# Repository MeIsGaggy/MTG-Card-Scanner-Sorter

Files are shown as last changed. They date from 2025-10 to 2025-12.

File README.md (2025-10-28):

# MTG Card Scanner

Using a lightly modified Creality Ender 3 S1, this is designed to be as non-destructive as possible. Every part in this repo can be 3D printed using whatever filament you want, while the stepper motor for the pick-up device is from the Sprite extruder. Everything can be put back together and used it as a 3D printer again. The only hardware I had to buy was vinyl tubing and a bellows suction cup. Both available on Amazon.

---

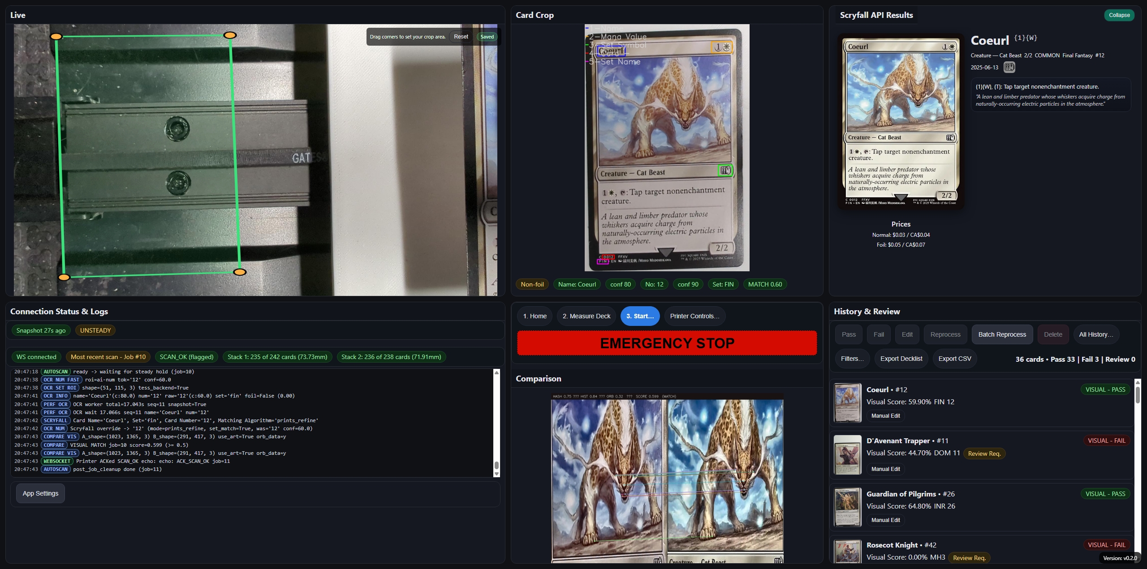
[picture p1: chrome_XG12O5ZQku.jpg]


---

## ⚠️ Disclaimers

* **3D Printer Hardware:** This is designed specifically for an Ender 3 S1. All STL files are modeled from that printer. They will not fit on any other printer. The motion limitations are also desgined for the Ender 3 S1. If you run this on another printer you may damage it.
* **Processing Speed:** This app is not designed to be the fasted available for scanning TCG cards. It was made as a personal project to make minimal modifications to a 3D printer running Klipper to have it sort through my thousands of Magic cards. Apps like Manabox are much faster, however they require manually holding or mounting the phone and running cards under. Even with a 3D printed holder, the reliablity is lackluster at times. This app tried to maintain performance on a Raspberry Pi while trying to keep reliablity as high as possible.
* **AI Assistance:** I am a hobbist, not a professional programmer. I combined my 8+ years of hobby/personal programming with ChatGPT to make something that would have either not been possible given my current skillset or would have taken so long I would have lost interest. If you are not a fan of AI assisted development, please look elsewhere.
* **Reliability:** I've done my best to get this to be as stable and reliable as possible so far. Based on my current testing it will correctly read the card over 90% of the time. Given the odd special foil or layout it may have a hard time. That's why I have a comaparison that runs after the OCR to compare the card scanned to the one it thinks it is. If it's below the set tollerance, it will flag it for manual review. 

---
## 🛠️Testing Hardware

* **Raspberry Pi 5 - 8GB**
* **Creatlity Ender 3 S1 Pro**
* **Google Pixel 7 Pro (as USB Webcam)**

---

## ✨ Features

* **One‑command start** via CLI: `mtg-scanner`
* **Live preview** with ROI (region-of-interest) overlay and steady‑frame auto‑capture
* **Rapid OCR** (RapidOCR ONNX) with optional **Tesseract fallback**
* **Card name matching** (configurable hashing/hist/ORB weights)
* **Scryfall**-powered lookups and price panel (with optional FX rate for CAD)
* **History & exports**: snapshots, thumbnails, and CSV/JSON exports
* **Update check** (optional) against your GitHub Releases on startup
* Designed to run well on **Raspberry Pi** (uses OpenCV headless)

---

## 📦 Installation

### Requirements

* Python **3.9+** (3.11 tested)
* A USB/UVC camera available as `/dev/video*`
* On Raspberry Pi OS / Debian, recommended system packages:

  ```bash
  sudo apt update
  sudo apt install -y tesseract-ocr libatlas-base-dev libjpeg-dev zlib1g-dev
  ```

### Download repository
```bash
gh repo clone MeIsGaggy/MTG-Card-Scanner-Sorter
cd MTG-Card-Scanner-Sorter/
```

### Create a virtualenv and install

From your project root (the folder containing `pyproject.toml`):

```bash
python -m venv .venv && source .venv/bin/activate
pip install --upgrade pip
pip install -e .        # editable install during development
# If OpenCV wheels complain, use headless:
pip uninstall -y opencv-python && pip install opencv-python-headless
```

## 🚨 3D printer running Klipper required!

This app specifically listens for signals from Moonraker. Moonraker runs on Klipper firmware and without it or a 3D printer you must edit the application to listen to mock READ_TO_SCAN signals. The app DOES have this functionality by default, all you need to do is send the SCAN_OK command to the printer and it will act as if it get a good scan from the app.

If you DO have a 3D printer running Klipper, downlaod the printer.cfg located in the repo and put it on your printers Klipper install. That contains all of the macros to use the app in it's current state.

All heaters are disabled in the printer.cfg to prevent fires. Do NOT use any other printer.cfg with this app unless you know what you're doing.

---

## 🔔 Updates

If there is an update available, it will be logged in the apps console. Run the following command to install the update

```bash
pip install --upgrade --force-reinstall \
  "git+https://github.com/MeIsGaggy/MTG-Card-Scanner-Sorter@[VERSION CODE]#egg=mtg_scanner"
```
Where it states [VERSION CODE] you need to paste the vX.X.X from the latest release
---

## 🚀 Quick start (Exports are optional)

```bash
export SETTINGS_PATH="./settings.json"          # optional (defaults to ./settings.json)
export MTG_SCANNER_REPO="<user>/<repo>"        # optional: enables the GitHub update check
mtg-scanner
```

Open a browser to `http://<raspberrypi>:5000` (or whatever host/port you configured).

> settings.json can be created within the app by opening the App Settings then clicking on Save.
> Repo does not need to be set. This is for following my updates, or can be changed to follow your own if you fork

---

## ⚙️ Configuration

Settings are read in this order **(env → `settings.json` → internal defaults)**. You can point the app to a custom config location via `SETTINGS_PATH`.

Create a `settings.json` next to where you run `mtg-scanner` (or copy `src/mtg_scanner/settings.example.json`):

```json
{
  "HOST": "0.0.0.0",
  "PORT": 5000,
  "CAMERA_DEVICE": "/dev/video0",
  "REQ_WIDTH": 1920,
  "REQ_HEIGHT": 1080,
  "REQ_FPS": 30,
  "OCR_BACKEND": "rapidocr,tesseract",
  "OCR_ONLY_ON_SNAPSHOT": true,
  "SHOW_ROI_OVERLAY": true,
  "SCRYFALL_TIMEOUT": 2.5,
  "FX_URL": "https://api.exchangerate.host/latest?base=USD&symbols=CAD",
  "FX_TTL_SEC": 43200,
  "DEBUG_LEVEL": 1
}
```

### Common keys (quick reference)

| Key | Default | What it does |
| --- | ---: | --- |
| `HOST` | `"0.0.0.0"` | Bind address for the web server. Use `127.0.0.1` to restrict to local only. |
| `PORT` | `5000` | Port for the web UI. |
| `CAMERA_DEVICE` | `"/dev/video0"` | Which camera device to open. |
| `REQ_WIDTH` / `REQ_HEIGHT` / `REQ_FPS` | `1920/1080/30` | Camera request settings (driver may choose the closest mode). |
| `OCR_BACKEND` | `"rapidocr,tesseract"` | Backends to try (RapidOCR first, fall back to Tesseract). |
| `OCR_ONLY_ON_SNAPSHOT` | `true` | If `true`, full OCR runs on snapshots; live OCR is throttled for speed. |
| `SHOW_ROI_OVERLAY` | `true` | Draws ROI boxes on the live preview. |
| `MATCH_ENABLE` | `1` | Enables name/image matching. |
| `MATCH_W_HASH`/`MATCH_W_HIST`/`MATCH_W_ORB` | see defaults | Relative weights when comparing frames to the reference. |
| `SCRYFALL_TIMEOUT` | `2.5` | Seconds to wait for Scryfall before skipping. |
| `FX_URL` / `FX_TTL_SEC` | see defaults | FX endpoint and TTL for USD→CAD price conversion. |
| `HISTORY_DIR` | `"./history"` | Where to persist JSON/thumbnail artifacts. |
| `JPEG_QUALITY_SNAP` | `82` | JPEG quality for stored snapshots. |

> Many more tuning options exist (detection thresholds, foil detection, ROI presets, debug switches). The defaults are sane—tune only if you need finer control.

---

## 🖥️ Using the App

The UI is split into panels:

* **Live** — camera feed with ROI overlay. Use the **Snapshot** action to lock a frame for OCR and matching. Live OCR is throttled unless you disable `OCR_ONLY_ON_SNAPSHOT`.
* **Detected Card** — the perspective‑corrected card image and parsed text.
* **Comparison** — quick visual comparison stats and matching scores.
* **Connection & Processing** — camera/processing status and log console. Use **Clear Logs** if needed.
* **Card Info & Prices** — Scryfall details, set symbol, and prices (optionally FX‑converted).

Additional actions:

* **History / Scans** — browse past captures, load a scan, or delete it.
* **Export** — export current/selected results to CSV/JSON (see the Export modal).
* **Settings** — open the settings modal to live‑tweak common options (also persisted via `settings.json`).

---

## 🧰 CLI and environment

* Start the app: `mtg-scanner`
* Override config file location: `export SETTINGS_PATH=/path/to/settings.json`
* Enable update check: `export MTG_SCANNER_REPO=<user>/<repo>`

---

## 🧪 API (advanced)

These are some of the commonly used endpoints that power the UI. Most users don’t need them directly, but they’re handy for automation.

* `GET /` — main UI
* `GET /api/state` — app state & stats
* `POST /api/snapshot` — take a snapshot
* `GET /api/scans` — list saved scans
* `POST /api/scan/<id>/load` — load a scan by id
* `GET /api/scan/<id>/thumb` — thumbnail
* `POST /api/scan/<id>/delete` — delete a scan
* `GET|POST /api/settings` — get/update settings
* `POST /api/logs/clear` — clear in‑app logs
* `GET /api/compare/stats` — comparison metrics
* `POST /api/badlist/add|remove|clear` — manage excluded results

> Endpoints may evolve; use your browser devtools (Network tab) to discover current calls from `ui.js`.

---

## 🛠️ Run as a service (Linux / Raspberry Pi)

Create `/etc/systemd/system/mtg-scanner.service`:

```ini
[Unit]
Description=MTG Scanner
After=network-online.target

[Service]
Type=simple
User=pi
WorkingDirectory=/home/pi/MTG_SCANNER_PROD
Environment=SETTINGS_PATH=/home/pi/MTG_SCANNER_PROD/settings.json
Environment=MTG_SCANNER_REPO=MeIsGaggy/MTG-Card-Scanner-Sorter
ExecStart=/home/pi/MTG_SCANNER_PROD/.venv/bin/mtg-scanner
Restart=on-failure

[Install]
WantedBy=multi-user.target
```

Then enable:

```bash
sudo systemctl daemon-reload
sudo systemctl enable --now mtg-scanner
```

---

## 🧩 Customizing & extending

* **UI tweaks**: edit `templates/index.html`, `static/css/app.css`, and `static/js/ui.js`. No restart is needed for minor CSS/JS in editable installs; otherwise restart the service.
* **Detection/OCR tuning**: adjust thresholds in `settings.json` (e.g., `RECTANGULARITY_MIN`, `TEXT_PRESENCE_MIN`, `MATCH_*` weights). Keep a backup of a good configuration.
* **Alternate currencies**: point `FX_URL` to another base/target pair or disable FX conversion in the UI.
* **Printer / Moonraker hooks**: `MOONRAKER_URL` and `HTTP_POST_URL` exist for optional integrations—leave them as defaults if unused.

## 📄 License

See **LICENSE** in this repository for the license. 

No commercial or for-profit use allowed.

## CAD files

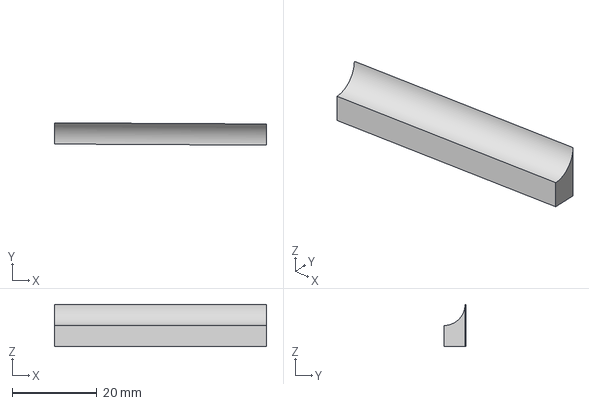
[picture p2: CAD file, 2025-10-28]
GCODE Files - NOT FOR FLASK/Printer Models/base_guide.3mf
50.0 x 5.27 x 10.0 mm

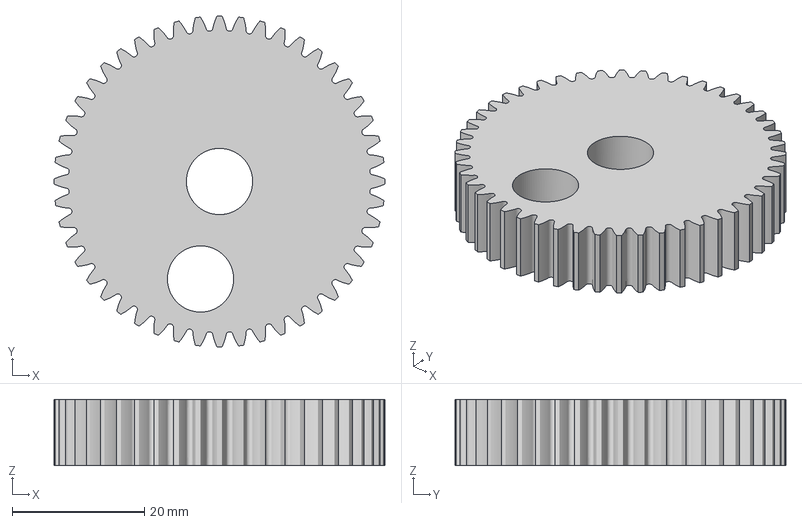
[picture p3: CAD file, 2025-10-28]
GCODE Files - NOT FOR FLASK/Syringe Push and Pull Module/gear_3_crank.3mf
50.0 x 50.0 x 10.0 mm

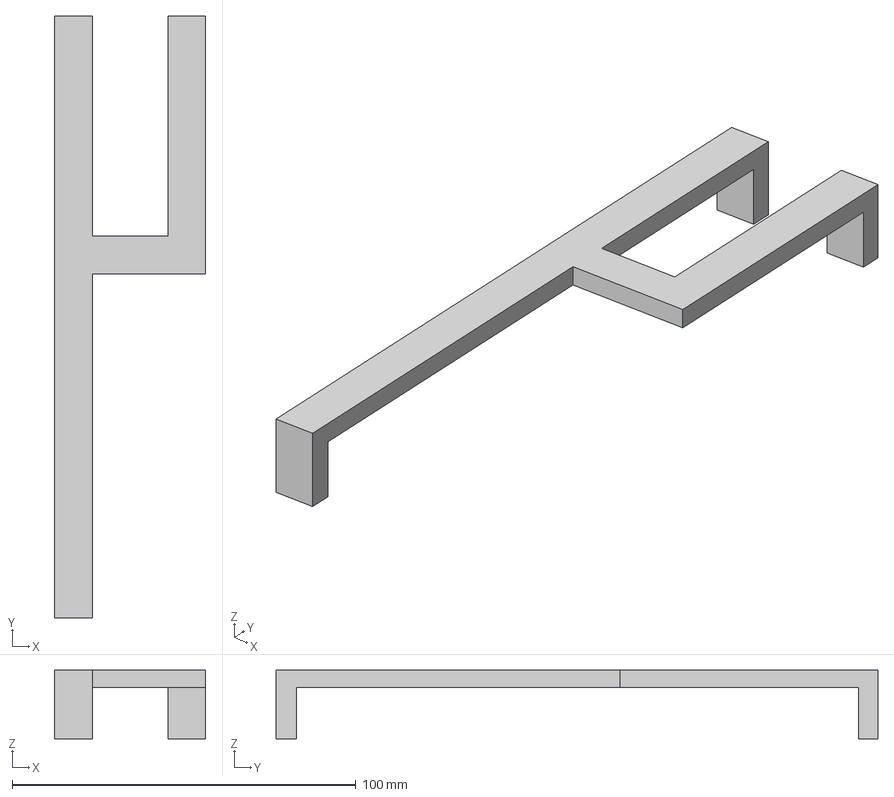
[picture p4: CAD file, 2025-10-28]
GCODE Files - NOT FOR FLASK/Printer Models/phone_lock_bracket.3mf
43.9 x 175.0 x 20.0 mm

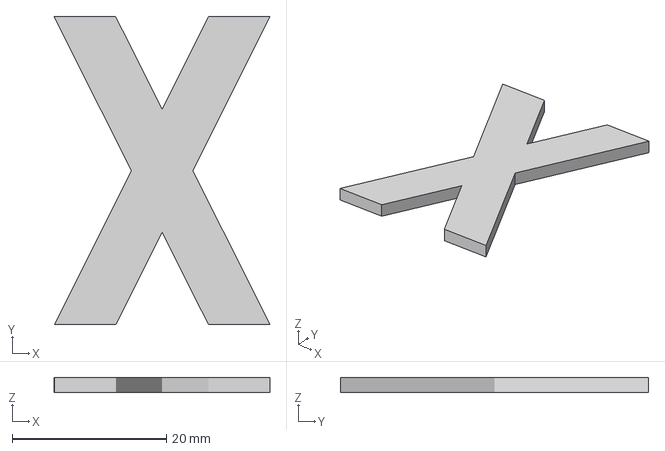
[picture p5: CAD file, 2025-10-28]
GCODE Files - NOT FOR FLASK/Syringe Push and Pull Module/anti_flex_plate.3mf
28.0 x 40.0 x 2.00 mm

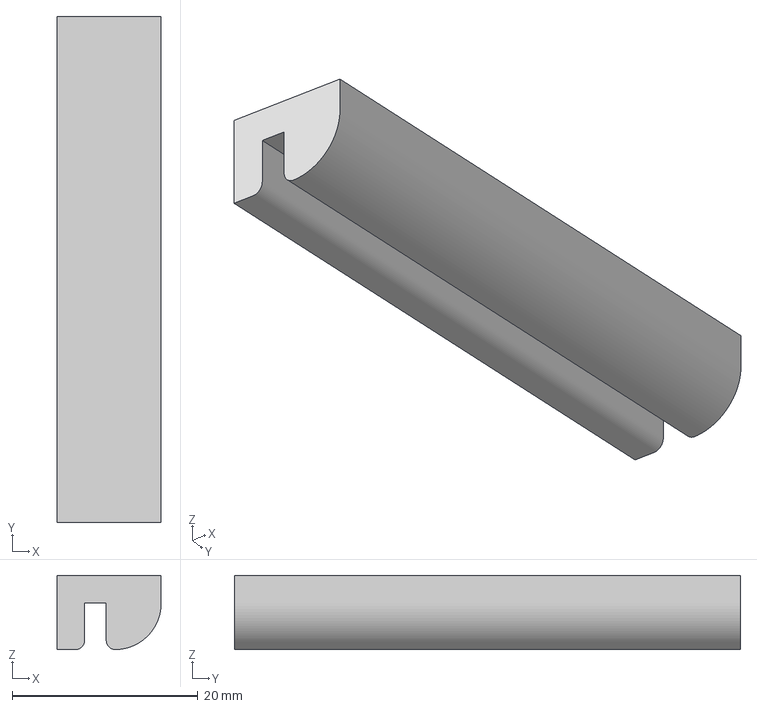
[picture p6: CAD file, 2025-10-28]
GCODE Files - NOT FOR FLASK/Printer Models/card_knocker.3mf
11.2 x 54.5 x 8.00 mm

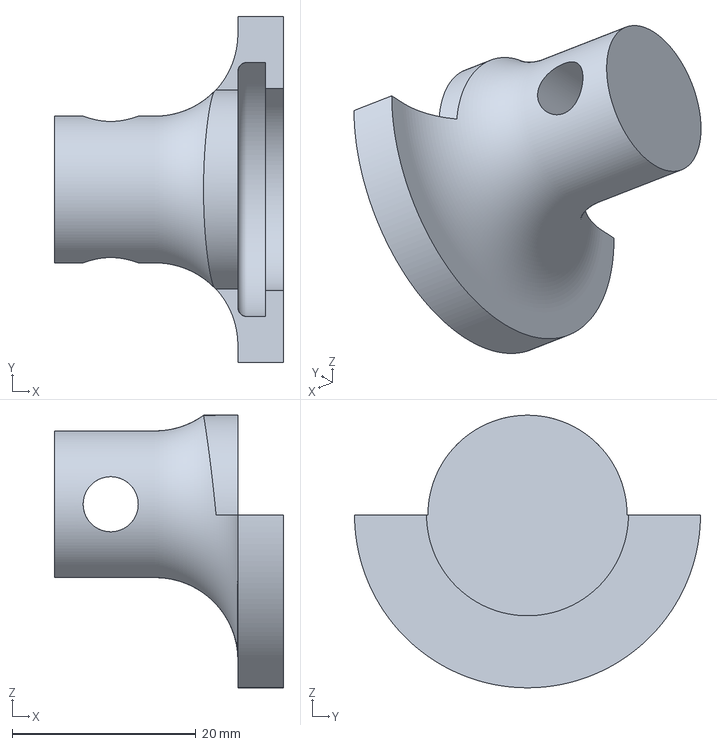
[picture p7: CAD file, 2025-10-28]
GCODE Files - NOT FOR FLASK/Syringe Push and Pull Module/syringe_plunger_adapter.3mf
25.0 x 37.7 x 29.7 mm

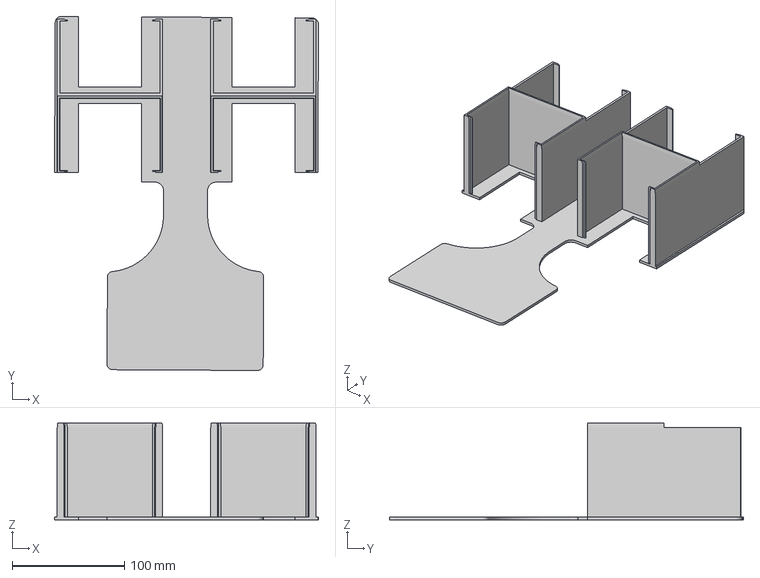
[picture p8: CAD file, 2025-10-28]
GCODE Files - NOT FOR FLASK/Printer Models/base_2_start_stack.3mf
235.7 x 315.9 x 86.5 mm

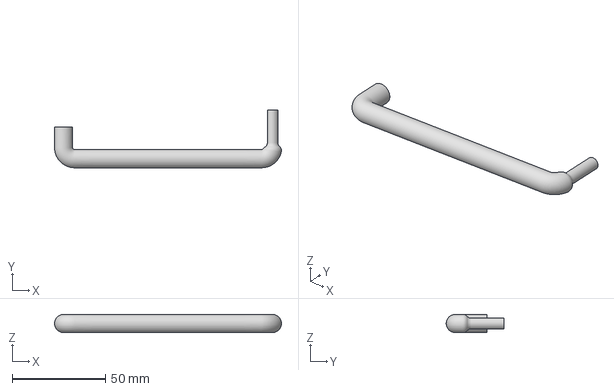
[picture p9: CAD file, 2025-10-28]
GCODE Files - NOT FOR FLASK/Syringe Push and Pull Module/crank_shaft.3mf
121.5 x 30.8 x 9.75 mm

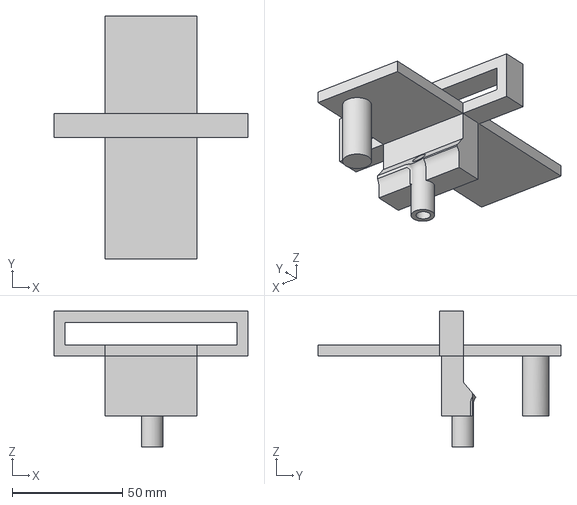
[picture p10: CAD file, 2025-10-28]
GCODE Files - NOT FOR FLASK/Printer Models/phone_holder_and_tube_guide.3mf
87.8 x 110.0 x 61.3 mm

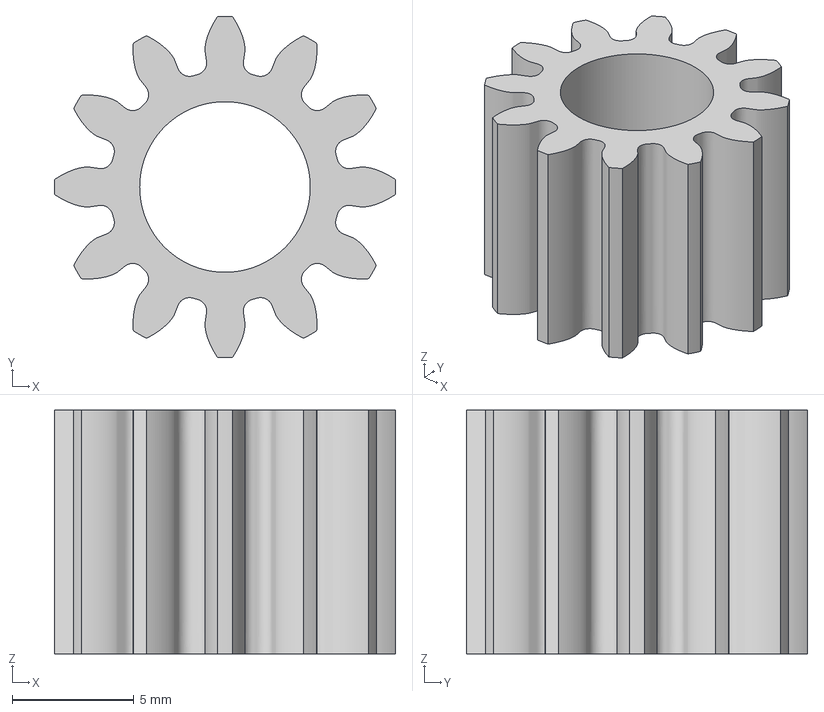
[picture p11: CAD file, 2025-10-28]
GCODE Files - NOT FOR FLASK/Syringe Push and Pull Module/gear_1_to_stepper.3mf
14.0 x 14.0 x 10.0 mm

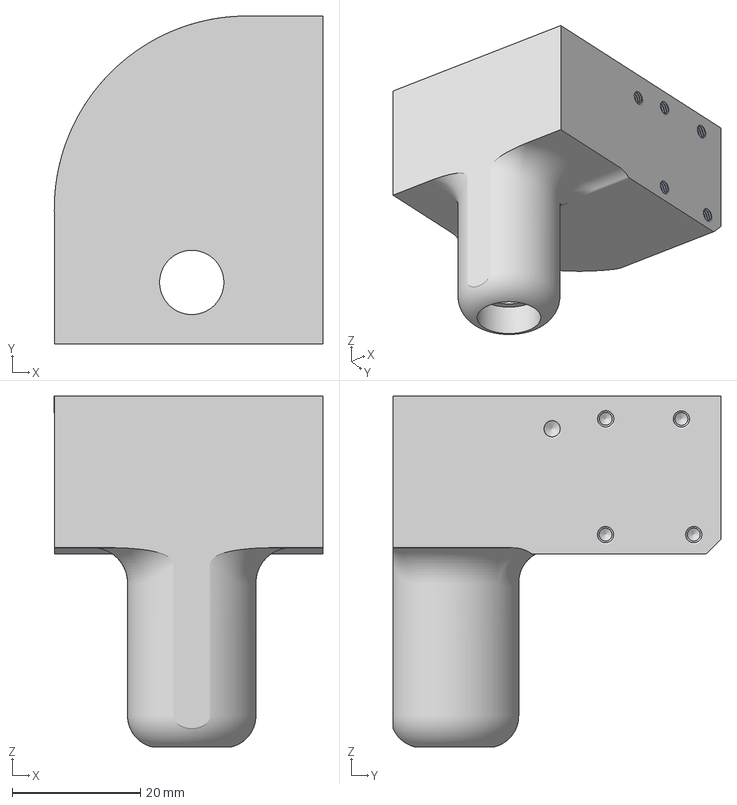
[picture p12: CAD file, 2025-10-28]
GCODE Files - NOT FOR FLASK/Printer Models/suction_head.3mf
41.8 x 51.1 x 54.6 mm

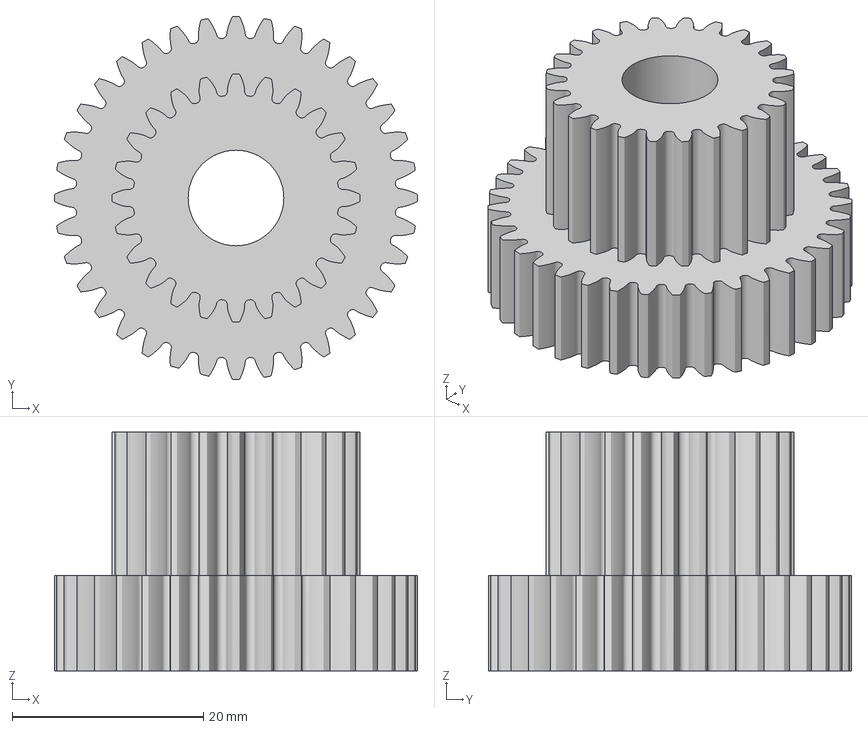
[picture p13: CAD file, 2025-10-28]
GCODE Files - NOT FOR FLASK/Syringe Push and Pull Module/gear_2_intermediate.3mf
38.0 x 38.0 x 25.0 mm

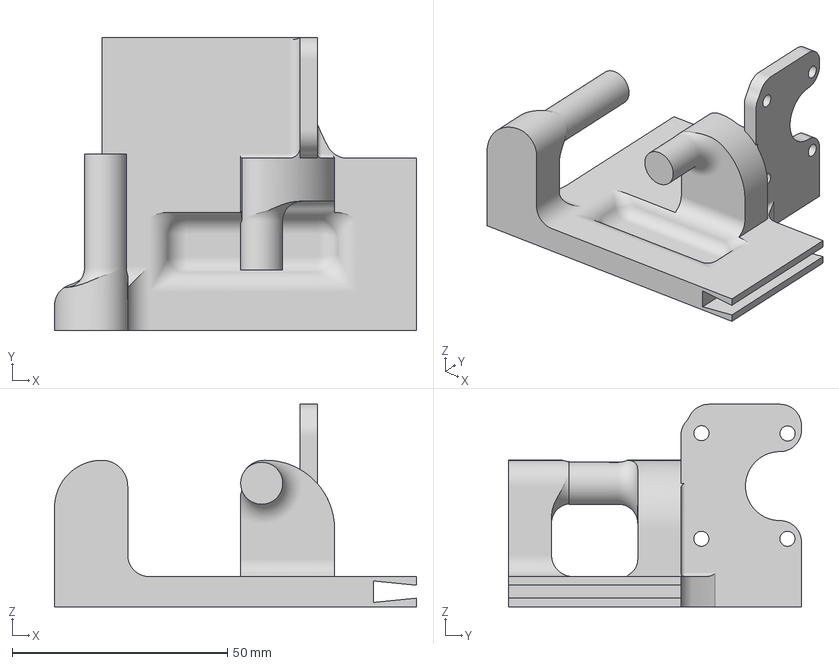
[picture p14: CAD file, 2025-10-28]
GCODE Files - NOT FOR FLASK/Syringe Push and Pull Module/stepper_gear_base.3mf
84.0 x 68.0 x 47.0 mm

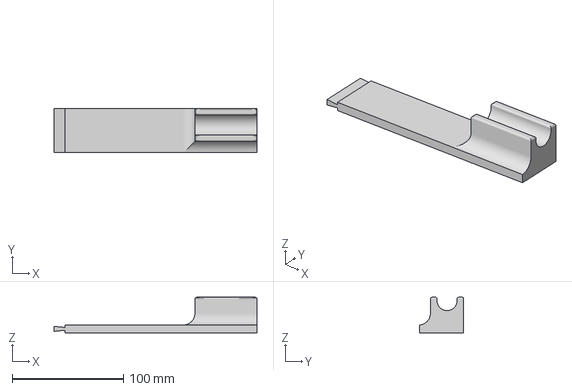
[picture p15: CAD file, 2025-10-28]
GCODE Files - NOT FOR FLASK/Syringe Push and Pull Module/syringe_base.3mf
182.7 x 40.0 x 32.0 mm

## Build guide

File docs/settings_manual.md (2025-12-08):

# Settings Reference (MTG Scanner)

How values flow: environment variables override `settings.json`, which overrides built‑in defaults in `config.py`. The UI reads from `/api/settings` and writes back to `settings.json`; most changes take effect immediately unless noted. Camera device/size/FPS and server bind (`HOST`/`PORT`) typically need a restart.

## Camera
- `CAMERA_DEVICE` — Video device path (e.g., `/dev/video0`).
- `REQ_WIDTH` / `REQ_HEIGHT` — Requested capture resolution; restart required.
- `REQ_FPS` — Requested capture frame rate; restart required.
- `FOURCC_PRIMARY` / `FOURCC_FALLBACK` — Preferred/backup pixel format codes.

## Processing & Canvas
- `PROC_MAX_WIDTH` / `PROC_DOWNSCALE_MAX_W` — Max width for processing and pre-detection downscale.
- `CARD_W` / `CARD_H` — Canvas size used for warping the card crop.
- `MIN_CARD_AREA_RATIO` / `MAX_CARD_AREA_RATIO` — Allowed card area as fraction of frame.
- `BORDER_MARGIN_PCT` — Padding around detected card to keep margins.
- `CARD_ASPECT` / `ASPECT_TOL` — Target aspect ratio and tolerance.
- `RECTANGULARITY_MIN` — Minimum rectangle score for a valid quad.
- `CARD_DETECT_MIN_SCORE` — Minimum score to treat a contour as a card.
- `CARD_RING_OUTSIDE_MIN_FRAC` — Required fraction of border that must live outside the card.
- `DETECT_QUAD_PAD_PCT` — Extra padding applied to detection quads before warp.
- `CARD_BG_BLUR` — Blur kernel size for background smoothing.
- `CARD_CLAHE_CLIP` / `CARD_CLAHE_TILE` — CLAHE parameters for card normalization.
- `CARD_BLACKHAT_KERNEL` — Kernel size for blackhat preprocessing on card masks.
- `CARD_CHANNEL_THRESH_C` — Constant added during channel thresholding.
- `CARD_MASK_MIN_COMPONENT` — Minimum connected component size for card masks.
- `CARD_MASK_BORDER_TRIM_PCT` — Border trim on masks to avoid edge artifacts.
- `CARD_EDGE_MIN_STRENGTH` / `CARD_EDGE_MIN_CONTRAST` / `CARD_EDGE_RING_FRAC` — Edge strength/contrast/ring guards for borders.
- `CARD_EDGE_SNAP_FRAC` — Snap factor when aligning detected edges.
- `CARD_EDGE_CONTRAST_WEIGHT` / `CARD_EDGE_CONTRAST_STEP` — Weight and step size when searching for edge contrast.
- `CARD_CROP_LIVE` — If false, keep the full frame in the live feed instead of the cropped card.
- `QUAD_STICKY_PX` — Pixel hysteresis applied to quad movement.
- `QUAD_SMOOTH_MIN_ALPHA` / `QUAD_SMOOTH_MAX_ALPHA` — Bounds for quad smoothing strength.
- `MANUAL_CROP_ENABLED` / `MANUAL_CROP_QUAD` — Enable and set manual quad points (UI drag handles).

## Tracking, Steady, Autoscan
- `CONFIRM_FRAMES` / `STALE_FRAMES` — Frames to confirm a card and to drop stale tracks.
- `MAX_ASSOC_DIST` — Max pixel distance to associate detections to tracks.
- `MAX_CARDS` — Limit of concurrent card tracks.
- `STEADY_MIN_FRAMES` / `STEADY_RELAX_FRAMES` — Frames required for steady state and relaxation.
- `STEADY_PROMOTE_S` — Time in steady before autoscan promotion.
- `AUTO_CAPTURE_WAIT_S` — Delay after READY_TO_SCAN before the snapshot (lets the stream settle).
- `AUTOSCAN_OCR_TIMEOUT` — Timeout for OCR after the snapshot.
- `DETECT_EVERY_N_FRAMES` / `DETECT_MAX_FPS` — Detection cadence caps.
- `FOIL_EVERY_N_FRAMES` — Interval for foil detection passes.
- `STEADY_SPEED_PX` — Speed threshold (px/frame) for steady detection.
- `LOCK_IOU_THRESH` — IoU threshold to lock a track to a detection.
- `ACQUIRE_FRAMES` / `DROP_MISS_FRAMES` / `PREDICT_HOLD` — Frames to acquire, drop, and hold predictions for a track.
- `TRACK_ALPHA` / `TRACK_BETA` / `TRACK_DEADBAND_PX` — Tracker smoothing and deadband weights.
- `TRACK_BOX_BLEND` — Blend factor when merging track boxes with new detections.
- `WARP_EXPAND_PCT` / `WARP_CROP_PCT` — Expand/crop percentages around warped cards.
- `MANUAL_SCAN_BYPASS_STEADY` — Allow manual scan without steady check.
- `FAST_OCR_MODE` — Favor speed for autoscan OCR.

## Capture & Orientation
- `SNAPSHOT_CARD_SCALE` — Upsample factor applied to saved/ocr snapshots.
- `AUTO_ORIENT` — Enable automatic card orientation.

## OCR & Debug
- `OCR_BACKEND` — Comma list of OCR backends to try.
- `OCR_ONLY_ON_SNAPSHOT` — If true, OCR only on captured snapshot (not live).
- `DEBUG_OCR` — Emit OCR debug logs.
- `OCR_DEBUG_BOXES` — Draw OCR boxes in the UI.
- `SHOW_ROI_OVERLAY` — Draw ROI overlays.
- `MIN_TITLE_LETTERS` — Minimum title length to accept.
- `TEXT_PRESENCE_MIN` — Text presence threshold for detecting text regions.
- `TITLE_ALLOW_TESS_FALLBACK` — Allow Tesseract fallback when primary fails.
- `USE_TESS_FOR_TITLES` — Force Tesseract for titles.
- `OCR_ENABLE_BLACKHAT` — Enable blackhat preprocessing on OCR crops.
- `LIVE_OCR_ONLY_WHEN_STEADY` / `LIVE_OCR_MIN_INTERVAL` — Gate live OCR to steady state and rate limit it.
- `OCR_SKIP_NUMBER` / `OCR_FAST_NUMBER_CONF_EXIT` — Skip collector number OCR or early-exit by confidence.
- `CARD_STREAM_LIVE` / `LIVE_CROP_WHILE_PAUSED` — Control live card crop display and whether the crop updates while paused.

## OCR Fast Path & Reprocess
- `OCR_FAST_PATH` / `OCR_LAZY_SET_HINT` — Enable fast OCR path and reuse set hints.
- `OCR_TITLE_SINGLE_PASS` — Single-pass title OCR (skip second attempt).
- `OCR_USE_EASYOCR` — Use EasyOCR shortcut flow.
- `OCR_TITLE_MAX_W` — Max width for title crop in fast path.
- `OCR_NUMBER_FASTPATH` — Enable fast-path number OCR.
- `REPROCESS_FORCE_FAST_OCR` — Force fast OCR during reprocess.
- `REPROCESS_MAX_WIDTH` — Downscale snapshot width before re-OCR (0 = off).
- `REPROCESS_SKIP_AI_ROIS` — Skip AI ROI refresh during reprocess.
- `REPROCESS_SKIP_FOIL_DETECT` — Skip foil detect during reprocess.

## Foil Detection
- `FOIL_MIN_SCORE` — Minimum foil score to consider foil.
- `FOIL_ON_TH` / `FOIL_OFF_TH` — Hysteresis thresholds to toggle foil state.
- `FOIL_DETECT` — Enable foil detection.

## Match / Comparison
- `MATCH_ENABLE` — Enable visual matching.
- `MATCH_W_HASH` / `MATCH_W_HIST` / `MATCH_W_ORB` — Weights for hash, histogram, and ORB scores.
- `MATCH_TH` — Overall match pass threshold.
- `NAME_OK_TH` — Name similarity threshold.
- `ALWAYS_SCAN_OK` — Force scan OK even if match fails.
- `MATCH_USE_ART` — Include art region in comparison.
- `MATCH_REQUIRE_ORB` — Require ORB match to pass.
- `MATCH_ORB_FAIL_THRESHOLD` — Threshold to flag ORB failure.
- `MATCH_ORB_FEATURES` — Number of ORB features to extract.
- `MATCH_FAST_ACCEPT_DELTA` / `MATCH_FAST_REJECT_DELTA` — Early accept/reject margins.
- `HASH_STABILITY_BITS` — Bits that must change before re-OCR triggers.

## Stream / UI Feeds
- `STREAM_ENABLED` — Enable MJPEG streaming.
- `STREAM_FPS` — Stream frame rate; defaults to camera FPS.
- `STREAM_JPEG_QUALITY` — JPEG quality for stream frames.
- `STREAM_WARP_DOWNSCALE` — Downscale factor before warping for stream only.
- `STREAM_CARD_SCALE` — Scale for card crop in UI stream.
- `SNAPSHOT_CARD_SCALE` — Upsample factor for saved/ocr snapshots.
- `CARD_STREAM_LIVE` / `LIVE_CROP_WHILE_PAUSED` — Send live card crops and keep updating while paused.
- `CARD_CROP_LIVE` — Show cropped card in the live feed instead of the full frame.

## Moonraker / Klipper
- `MOONRAKER_URL` — WebSocket URL to Moonraker.
- `HTTP_POST_URL` — HTTP endpoint for G-code script posting.
- `REQUIRE_PRINTER_ACK` — Wait for printer ACK before proceeding.

## Stacks / Sorter
- `CARD_THICKNESS_MM` — Card thickness estimate pushed to Klipper.
- `REMEASURE_EVERY` — Cards between auto re-measure; 0 disables mid-run probe.

## AI / YOLOv5
- `AI_ENABLED` — Master AI toggle.
- `AI_USE_FOR_CARDS` / `AI_USE_FOR_ROIS` — Use AI to find card box / ROIs.
- `AI_ONLY_MODE` — Use AI ROIs only (ignore static ROIs).
- `AI_MODEL_PATH` — Path to YOLO model.
- `YOLOV5_DIR` — Local YOLOv5 repo path.
- `AI_IMG_SIZE` — Inference image size.
- `AI_CONF_THRES` / `AI_IOU_THRES` — Confidence and IoU thresholds.
- `AI_MAX_DETS` — Maximum detections per inference.
- `AI_CLASS_NAMES` — Class labels list (order-sensitive).
- `AI_BOX_THICKNESS` / `AI_LEGEND_FONT_SCALE` / `AI_LEGEND_FONT_THICKNESS` / `AI_LEGEND_LINE_THICKNESS` / `AI_LEGEND_PAD` — Overlay settings for AI debugging legends.
- `AI_CARD_MIN_CONF`, `AI_SETNAME_MIN_CONF`, `AI_SETNAME_MIN_Y`, `AI_SETNAME_MAX_Y`, `AI_SETNAME_MIN_WIDTH`, `AI_SETNAME_MIN_HEIGHT`, `AI_CARD_MIN_AREA`, `AI_CARD_MAX_TOP` — Heuristics to filter detections by confidence, position, and size.
- `AI_NAME_PAD_X` / `AI_NAME_PAD_Y` — Padding applied to name ROI.
- `AI_TOPLINE_FRAC_MIN` / `AI_TOPLINE_MULT` — Heuristics for merging text lines.
- `AI_CARD_PAD_LEFT` / `AI_CARD_PAD_RIGHT` / `AI_CARD_PAD_Y` — Extra padding around detected cards before ROI extraction.
- `SET_ICON_FALLBACK_ENABLE` / `SET_NAME_FALLBACK_ENABLE` — Fall back to set icon/name heuristics when OCR fails.

## Export & Caches
- `EXPORT_DIR` — Export output directory.
- `SC_IMG_CACHE_DIR` — Scryfall image cache directory.
- `SCRY_IMG_LRU_MAX` / `SCRY_FEATS_LRU_MAX` — In-memory LRU sizes for images/features.
- `SCRY_SETS_CACHE_PATH` / `SCRY_SETS_CACHE_TTL_S` — Cache path and TTL for Scryfall set data.

## Scryfall & Prices
- `SCRYFALL_TIMEOUT` — HTTP timeout for Scryfall calls.
- `FX_URL` — Exchange rate API URL.
- `FX_TTL_SEC` — Cache TTL for FX data.

## Appearance / Photometric
- `APPEARANCE_ALIGN_ENABLE` — Enable appearance alignment.
- `APPEARANCE_AB_STRENGTH` / `APPEARANCE_SAT_STRENGTH` — Chroma and saturation match strengths.
- `APPEARANCE_GAMMA_CLAMP` — Allowed gamma clamp range.
- `TONE_ALIGN_ENABLE` — Enable tone alignment.

## Persistence & Server
- `HISTORY_DIR` / `HISTORY_IMG_DIR` — History storage paths.
- `HISTORY_JSON_EXT` — Extension for history JSON files.
- `JPEG_QUALITY_SNAP` / `JPEG_QUALITY_CMP` / `JPEG_QUALITY_THUMB` — JPEG qualities.
- `HISTORY_API_DEFAULT_LIMIT` / `HISTORY_API_MAX_LIMIT` — API pagination limits.
- `HOST` / `PORT` — Server bind address/port; restart required.

## Debug / Paths / Performance
- `DEBUG_LEVEL` — Verbosity level.
- `DEBUG_SAVE_ROI` — Save ROI crops.
- `DEBUG_DIR` — Directory for debug artifacts.
- `BAD_DIR` — Directory for bad-list images.
- `USE_OPENCL` — Allow OpenCL acceleration when available.

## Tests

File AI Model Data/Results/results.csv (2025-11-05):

epoch | train/box_loss | train/obj_loss | train/cls_loss | metrics/precision | metrics/recall | metrics/mAP_0.5 | metrics/mAP_0.5:0.95 | val/box_loss | val/obj_loss | val/cls_loss | x/lr0 | x/lr1 | x/lr2
0 | 0.10964 | 0.039257 | 0.04689 | 0.005422 | 0.26599 | 0.01826 | 0.004048 | 0.086834 | 0.035313 | 0.03565 | 0.0748 | 0.0028 | 0.0028
1 | 0.085968 | 0.039998 | 0.032323 | 0.26259 | 0.29595 | 0.05763 | 0.021313 | 0.08709 | 0.029912 | 0.025139 | 0.048644 | 0.0056436 | 0.0056436
2 | 0.078617 | 0.034368 | 0.023455 | 0.07547 | 0.27515 | 0.06904 | 0.013564 | 0.090034 | 0.023735 | 0.017189 | 0.02243 | 0.0084297 | 0.0084297
3 | 0.077252 | 0.028146 | 0.017608 | 0.2987 | 0.74466 | 0.47203 | 0.15206 | 0.068803 | 0.02081 | 0.013595 | 0.009703 | 0.009703 | 0.009703
4 | 0.071493 | 0.024177 | 0.01427 | 0.42542 | 0.54384 | 0.37361 | 0.11619 | 0.066754 | 0.018996 | 0.0087561 | 0.009703 | 0.009703 | 0.009703
5 | 0.066223 | 0.022305 | 0.01041 | 0.41079 | 0.90771 | 0.57121 | 0.15114 | 0.069385 | 0.016911 | 0.0061492 | 0.009604 | 0.009604 | 0.009604
6 | 0.059028 | 0.02084 | 0.0086906 | 0.41022 | 0.88958 | 0.52366 | 0.18978 | 0.057659 | 0.014983 | 0.004865 | 0.009505 | 0.009505 | 0.009505
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

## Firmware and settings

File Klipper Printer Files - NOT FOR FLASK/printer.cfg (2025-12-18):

# ============================== CARD SCANNER CONFIG (Ender 3 S1 + Klipper) ==============================
# Motion-only setup for MTG card sorting. Heaters/fans are neutralized. Scanner app drives pass/fail.

[delayed_gcode INIT_VAC_ZERO]
initial_duration: 1
gcode:
  # Define current physical position as OFF=0 at firmware start
  MANUAL_STEPPER STEPPER=VAC SET_POSITION=0

# ===== UI Helpers =====
[gcode_macro SORTER_HELP]
description: Show the short how-to for the card scanner
gcode:
  { action_respond_info(
    "CARD SCANNER — Quick start:\\n"
    "1) SORTER_HOME (or RUN_SORTER_INTERACTIVE COUNT=1 HOME=1)\\n"
    "2) SET_START_HEIGHT_GUIDED  -> then SET_START_HEIGHT_OK (measures Start1 & Start2)\\n"
    "3) SORT_ONE (or SORT_10). While at scan, your app sends SCAN_OK / SCAN_FAIL.\\n"
    "Useful: SHOW_STACKS, CANCEL_SCAN_WAIT, SET_TIMEOUT_S VALUE=<sec> (0=infinite)"
  ) }

[gcode_macro SORT_ONE]
description: Pick 1 card and run one full scan/place cycle
gcode:
  RUN_SORTER_INTERACTIVE COUNT=1 HOME=0

[gcode_macro SORT_10]
description: Pick and process 10 cards
gcode:
  RUN_SORTER_INTERACTIVE COUNT=10 HOME=0

[gcode_macro SET_TIMEOUT_S]
description: Set scan wait timeout (seconds). 0 = wait forever (no auto-fail)
gcode:
  {% set V = params.VALUE|default(0)|int %}
  SET_GCODE_VARIABLE MACRO=SORTER_PARAMS VARIABLE=scan_timeout_s VALUE={V}
  { action_respond_info("Scan timeout set to %s" % ("infinite" if V==0 else ("%ds" % V))) }

[gcode_macro CANCEL_SCAN_WAIT]
description: Cancel any active scan wait / countdown ticks
gcode:
  SET_GCODE_VARIABLE MACRO=VISION_STATE VARIABLE=busy VALUE=0
  SET_GCODE_VARIABLE MACRO=VISION_STATE VARIABLE=timer_left  VALUE=0
  SET_GCODE_VARIABLE MACRO=VISION_STATE VARIABLE=timer_total VALUE=0
  UPDATE_DELAYED_GCODE ID=VISION_TIMEOUT DURATION=0
  UPDATE_DELAYED_GCODE ID=VISION_TICK    DURATION=0
  RESPOND PREFIX=info MSG="Scan wait cancelled."

# ===== Includes / Core =====
[include fluidd.cfg]
# [include timelapse.cfg]

[mcu]
serial: /dev/serial/by-id/usb-1a86_USB_Serial-if00-port0
restart_method: command

[printer]
kinematics: cartesian
max_velocity: 100
max_accel: 750
max_z_velocity: 100
max_z_accel: 500
square_corner_velocity: 5.0

# ----- Axes -----
[stepper_x]
step_pin: PC2
dir_pin: PB9
enable_pin: !PC3
microsteps: 16
rotation_distance: 40
endstop_pin: !PA5
position_endstop: -10
position_max: 235
position_min: -15
homing_speed: 50

[stepper_y]
step_pin: PB8
dir_pin: PB7
enable_pin: !PC3
microsteps: 16
rotation_distance: 40
endstop_pin: !PA6
position_endstop: -8
position_max: 240
position_min: -13
homing_speed: 50

[stepper_z]
step_pin: PB6
dir_pin: !PB5
enable_pin: !PC3
microsteps: 16
rotation_distance: 8
endstop_pin: probe:z_virtual_endstop
position_max: 270
position_min: -10
homing_speed: 10

# ----- Probe (BLTouch) -----
[bltouch]
sensor_pin: ^PC14
control_pin: PC13
x_offset: -31.8
y_offset: -40.5
z_offset: 4.085
probe_with_touch_mode: true
stow_on_each_sample: false
samples: 1
samples_tolerance: 0.1
samples_tolerance_retries: 2
speed: 20.0

# === Custom safe home (unchanged) ===
[homing_override]
set_position_z: 0
axes: xyz
gcode:
  G90
  G1 Z75 F1200
  G28 X Y
  G1 X104 Y10 F6000
  G28 Z

# Optional: bed mesh
[bed_mesh]
speed: 120
mesh_min: 10, 10
mesh_max: 200, 194
probe_count: 4,4
algorithm: bicubic
fade_start: 1
fade_end: 10
fade_target: 0

# ----- QoL -----
[respond]
[display_status]
[pause_resume]
recover_velocity: 25
[idle_timeout]
timeout: 1800

[temperature_sensor raspberry_pi]
sensor_type: temperature_host
min_temp: 10
max_temp: 100

# ----- Neutralize print-related G-codes -----
[gcode_macro M104]
description: NO-OP (heating disabled)
gcode:
  RESPOND PREFIX=warn MSG="M104 ignored: heaters disabled"

[gcode_macro M109]
description: NO-OP (heating disabled)
gcode:
  RESPOND PREFIX=warn MSG="M109 ignored: heaters disabled"

[gcode_macro M140]
description: NO-OP (bed heating disabled)
gcode:
  RESPOND PREFIX=warn MSG="M140 ignored: bed disabled"

[gcode_macro M190]
description: NO-OP (bed heating disabled)
gcode:
  RESPOND PREFIX=warn MSG="M190 ignored: bed disabled"

[gcode_macro M106]
description: NO-OP (fans repurposed later)
gcode:
  RESPOND PREFIX=info MSG="M106 ignored: fans disabled"

[gcode_macro M107]
description: NO-OP
gcode:
  RESPOND PREFIX=info MSG="M107 ignored: fans disabled"

# ===== Sorter Coordinates / Motion Tunables =====
[gcode_macro SORTER_PARAMS]
# --- SCAN AREA (single) ---
variable_scan_xy:     118.0, 0.0  # one scan area only
# --- REJECT AREA (single) ---
variable_reject_xy:    53.80, 61.0

# --- LEGACY single-stack aliases (kept for compatibility; not used by new logic) ---
variable_input_xy:    120.0, 220.0
variable_finish_xy:    53.80, 61.0

# --- NEW: dual starts & dual finishes (EDIT THESE 4) ---
variable_input1_xy:   44.0, 225.0   # Start stack 1  ← set yours
variable_input2_xy:   181.0, 225.0   # Start stack 2  ← set yours
variable_finish1_xy:   45.0, 156.30   # Finish stack 1 ← set yours
variable_finish2_xy:   182.20, 156.30  # Finish stack 2 ← set yours

# Tool XY offset if your picker isn't centered to nozzle coords
variable_tool_offset_x: 0.0
variable_tool_offset_y: 0.0

# Heights & speeds
variable_clearance_z: 60.0         # minimum safe Z
variable_travel_z:    110.0         # travel height for XY moves while holding a card
variable_approach_z:  2.0
variable_pick_z:      -0.25
variable_place_z:     0.8
variable_pick_guard:  -2.5
variable_min_z_floor: -3.0
variable_empty_z:      4.0           # <= this Z means "no card"

# Scan plane & head park pose (single scan area)
variable_scan_drop_z:   0.0           # Z where the card rests for scanning (bed plane)
variable_scan_pick_delta:   0.0           # +mm press when picking from scan (0 = same as drop)
variable_scan_head_xy: 124.0, 117.0   # HEAD PARK XY during scan
variable_scan_head_z:  70.0          # HEAD PARK Z during scan
variable_finish_drop_z: 88.085          # Z to drop card for PASS
variable_reject_drop_z: 88.085          # Z to drop card for FAIL
variable_scan_h:        0.0           # legacy (not used for motion)
variable_xy_speed:    7000
variable_z_speed:     1250

# Timings (ms)
variable_dwell_pick_ms:     500
variable_dwell_scan_ms:     500
variable_dwell_release_ms:  200
variable_lift_after_pick:    75.0
variable_dwell_drop_ms:     500

# Probe speeds
variable_probe_fast: 100.0
variable_probe_slow: 50.0

# Vacuum tuning — simple symmetric half-turns
variable_vac_half_rev: 12.741
variable_vac_speed:    15
variable_vac_dwell_ms: 120
variable_pick_z_start: -2.5

# Shake (hitchhiker guard)
variable_shake_enable:        1
variable_shake_lift:          2.5
variable_shake_duration_ms:   500
variable_shake_step:          0.10
variable_shake_pulse_ms:      10
variable_shake_speed:         8000
variable_shake_accel:         8000

# Scan wait behavior
variable_scan_timeout_s:    0
variable_scan_warn_step_s: 10
variable_timeout_auto_fail: 0
gcode:
  G4 P0

# ===== Dynamic Stack Heights (DUAL) =====
[gcode_macro STACK_STATE]
variable_card_thickness: 0.305
variable_cards1_total: 0
variable_cards2_total: 0
variable_cards_since_measure: 0
variable_remeasure_every: 0
variable_last_meas1: 0.0
variable_last_meas2: 0.0
variable_last_cards1: 0
variable_last_cards2: 0
variable_start1_cards_est: 0.0
variable_start2_cards_est: 0.0
# start stacks (measured separately)
variable_start1_h: 0.0
variable_start2_h: 0.0
variable_start1_empty: 0
variable_start2_empty: 0
variable_last_probe_z: 0.0
variable_last_probe_slot: 0
variable_pending_pick: 0
# finish stacks (running totals)
variable_finish1_h: 0.0
variable_finish2_h: 0.0
variable_reject_h:  0.0
# which stack to pick next / which finish to drop next
variable_next_start_slot: 1
variable_next_finish_slot: 1
# source start slot of the *current* card (set by PICKUP_CARD)
variable_src_slot: 0
gcode: G4 P0

# ===== Vacuum Plunger Stepper (compound 1->3, 2->4; 3/2 same axle) =====
[manual_stepper VAC]
step_pin: PB4
dir_pin: PB3                      # ON = +X, OFF = −X (non-inverted)
enable_pin: !PC3
microsteps: 16
rotation_distance: 25.482
gear_ratio: 3:1, 2:1              # overall 6:1
full_steps_per_rotation: 200
velocity: 100
accel: 400
position_min: -200
position_max:  200

# ===== Setup / Calibration =====
[gcode_macro SORTER_HOME]
description: Home and raise to safe Z
gcode:
  G90
  G28
  _STOW_PROBE
  _SAFE_RAISE
  RESPOND PREFIX=info MSG="Homed. Stack probe will measure each pickup."

[gcode_macro SET_START_HEIGHT_GUIDED]
description: Move to safe Z and prompt to place start stacks
gcode:
  {% set P = printer["gcode_macro SORTER_PARAMS"] %}
  G90
  {% if printer.toolhead.position.z|float < P.clearance_z %}
    G1 Z{P.clearance_z} F{P.z_speed}
  {% endif %}
  G1 Z100 F{P.z_speed}
  RESPOND PREFIX=info MSG="Place BOTH START stacks, then run: SET_START_HEIGHT_OK"
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

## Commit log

2025-08-23 Added printer config file
    [printer.cfg]
2025-08-23 Updated printer.cfg
    [printer.cfg]
2025-10-05 New 2-stack sorting
    - Added logic for picking from two stacks intead of one
    - Added logic for dropping into two stacks intead of one
    - Stacks one and two are alternated while picking and dropping
    - Added printer motion controls with a D-pad style control scheme
    - Added emergency stop to shutdown printer
    - Added card detection ROI memory (when ROI is set it persists through app restarts)
    [printer.cfg]
2025-10-06 v0.1 STL models
    This entire program is designed around the use of these files.
    [anti_flex_plate.3mf, base_2_start_stack.3mf, base_guide.3mf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]
2025-11-05 v0.1.5 - AI Detection
    Now uses a trained AI model to detect keys on MTG cards instead of hard-coded ROIs for OCR
    AI was trained on a Raspberry Pi 5 with the only non-stock addition being an NVME HAT
    App has fallback logic for alternator layouts. If there is no set code or collector number detected, it will use the set icon if it detects it then compares that icon to a known list of icons. This i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
    App can run on its own with little to no intervention. The odd card gets dropped at an odd angle and needs to be adjusted
    [results.csv]
2025-12-08 v0.2 - Major improvements App: - Reworked live stream detection to simple snapshot within set ROI by the user (card detection was being annoying and unstable) - Removed unused logic - Increased relia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
    [printer.cfg]
2025-12-18 v0.2.1 - Batch Reprocessing, New Pick Logic and Bux Fixes
    - Implemented batch reprocessing. Failed cards are counted, queued for reprocess then reprocessed one by one. The user is presented with a list of each card upon completion
    - Implemented quarantine review for bad json saves. Includes auto-fix but also has fields to manually edit
    - Fixed a websocket error causing timeout
    - Console extends up and down to match screen height
    - Reworked how the printer picks up cards. Old logic was to measure each deck and keep track or heights. Now logic uses BLTouch to probe the stacks every time it moves down to pick up a card. This removes a step at start up, removes the need to remeasure the deck and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
